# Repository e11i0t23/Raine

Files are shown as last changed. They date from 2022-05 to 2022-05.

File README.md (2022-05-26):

# Raine PCB

PCB for the Raine by AKB, Please note the open source version has a reset button added to underside for compatibility with jlcpcb assembly 

---
##### Please Note these PCBs are provided under the MIT Liscence
---

### How to order
The steps bellow outline how to order this pcb with assembly through the JLCPCB platform  

1) From the releases section download CAMOutputs.zip, BOM_Raine.xlsx, and PNP_Raine_Back.xlsx
2) Load the new order section of Jlcpcb, uploading CamOutputs.zip as gerber file
3) Most settings can be left as defualt, reccomend selecting LeadFree HASL under surface finish,
    (Note only Green or Black soldermask can be used with assembly)
4) Enable PCB assembly, choose wanted quantity, and select assemble bottom side then press next
5) For the Bom upload the file BOM_Raine.xlsx, for CPL upload PNP_Raine_Back.xlsx, then press next
6) Ensure file has loaded and no items show out of stock, then press next followed by add to basket
7) Once PCB has arrived QMK firmware can be flashed

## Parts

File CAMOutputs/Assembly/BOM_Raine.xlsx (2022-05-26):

Qty | Value | Device | Package | LCSC Part Number | Parts
74 | 1n4148W | D_SOD123-SOD-123 | SOD-123 | C81598 | D0, D1, D2, D3, D4, D5, D6, D7, D8, D9, DA, DALT, DB, DBACKSPACE, DBACKSPACE2, DC, DCAPSLOCK, DCTRL, DD, DDEL, DE, DESC, DF, DFN, DG, DH, DI, DINSERT, DJ, DK, DKP_0, DKP_1, DKP_2, DKP_3, DKP_4, DKP_5, DKP_6, DKP_7, DKP_8, DKP_9, DL, DM, DMENU, DN, DNUMLOCK, DO, DP, DQ, DR, DS, DSCROLLLOCK, DSHIFT, DSHIFT2, DSPACE, DSPACE3, DSPACE4, DSPACE6, DSPACE10, DSPACE11, DSPACE12, DSPACE13, DSPACE14, DSPACE15, DSPACE16, DSPACE17, DT, DTAB, DU, DV, DW, DWIN, DX, DY, DZ
4 | 100nf | Capacitor | C0603 | C14663 | C4, C5, C6, C7
2 | 10K | Resistor | R0603 | C25197 | R1, R2
1 | 1uF | Capacitor | C0603 | C15849 | C3
2 | 22omh | Resistor | R0603 | C22961 | R5, R6
2 | 22pF | Capacitor | C0603 | C1653 | C1, C2
1 | 4.7uF | Capacitor | C0603 | C19666 | C8
2 | 5.1k | Resistor | R0603 | C23186 | R3, R4
1 | 16MHZ | Crystal | CR3225 | C13738 | CR1
1 | ATMEGA32U4 | ATMEGA32U4-AUR44ML-L | 44ML-L | C44854 | U2
2 | Reset switch | TL3342F160QG/TR | SW_TL3342F160QG/TR | C388295 | SW1, SW2
1 | USB-C-M12-TYPE-C-31-M12 | USB-C-M12-TYPE-C-31-M12 | TYPE-C-31-M-12 | C165948 | J1

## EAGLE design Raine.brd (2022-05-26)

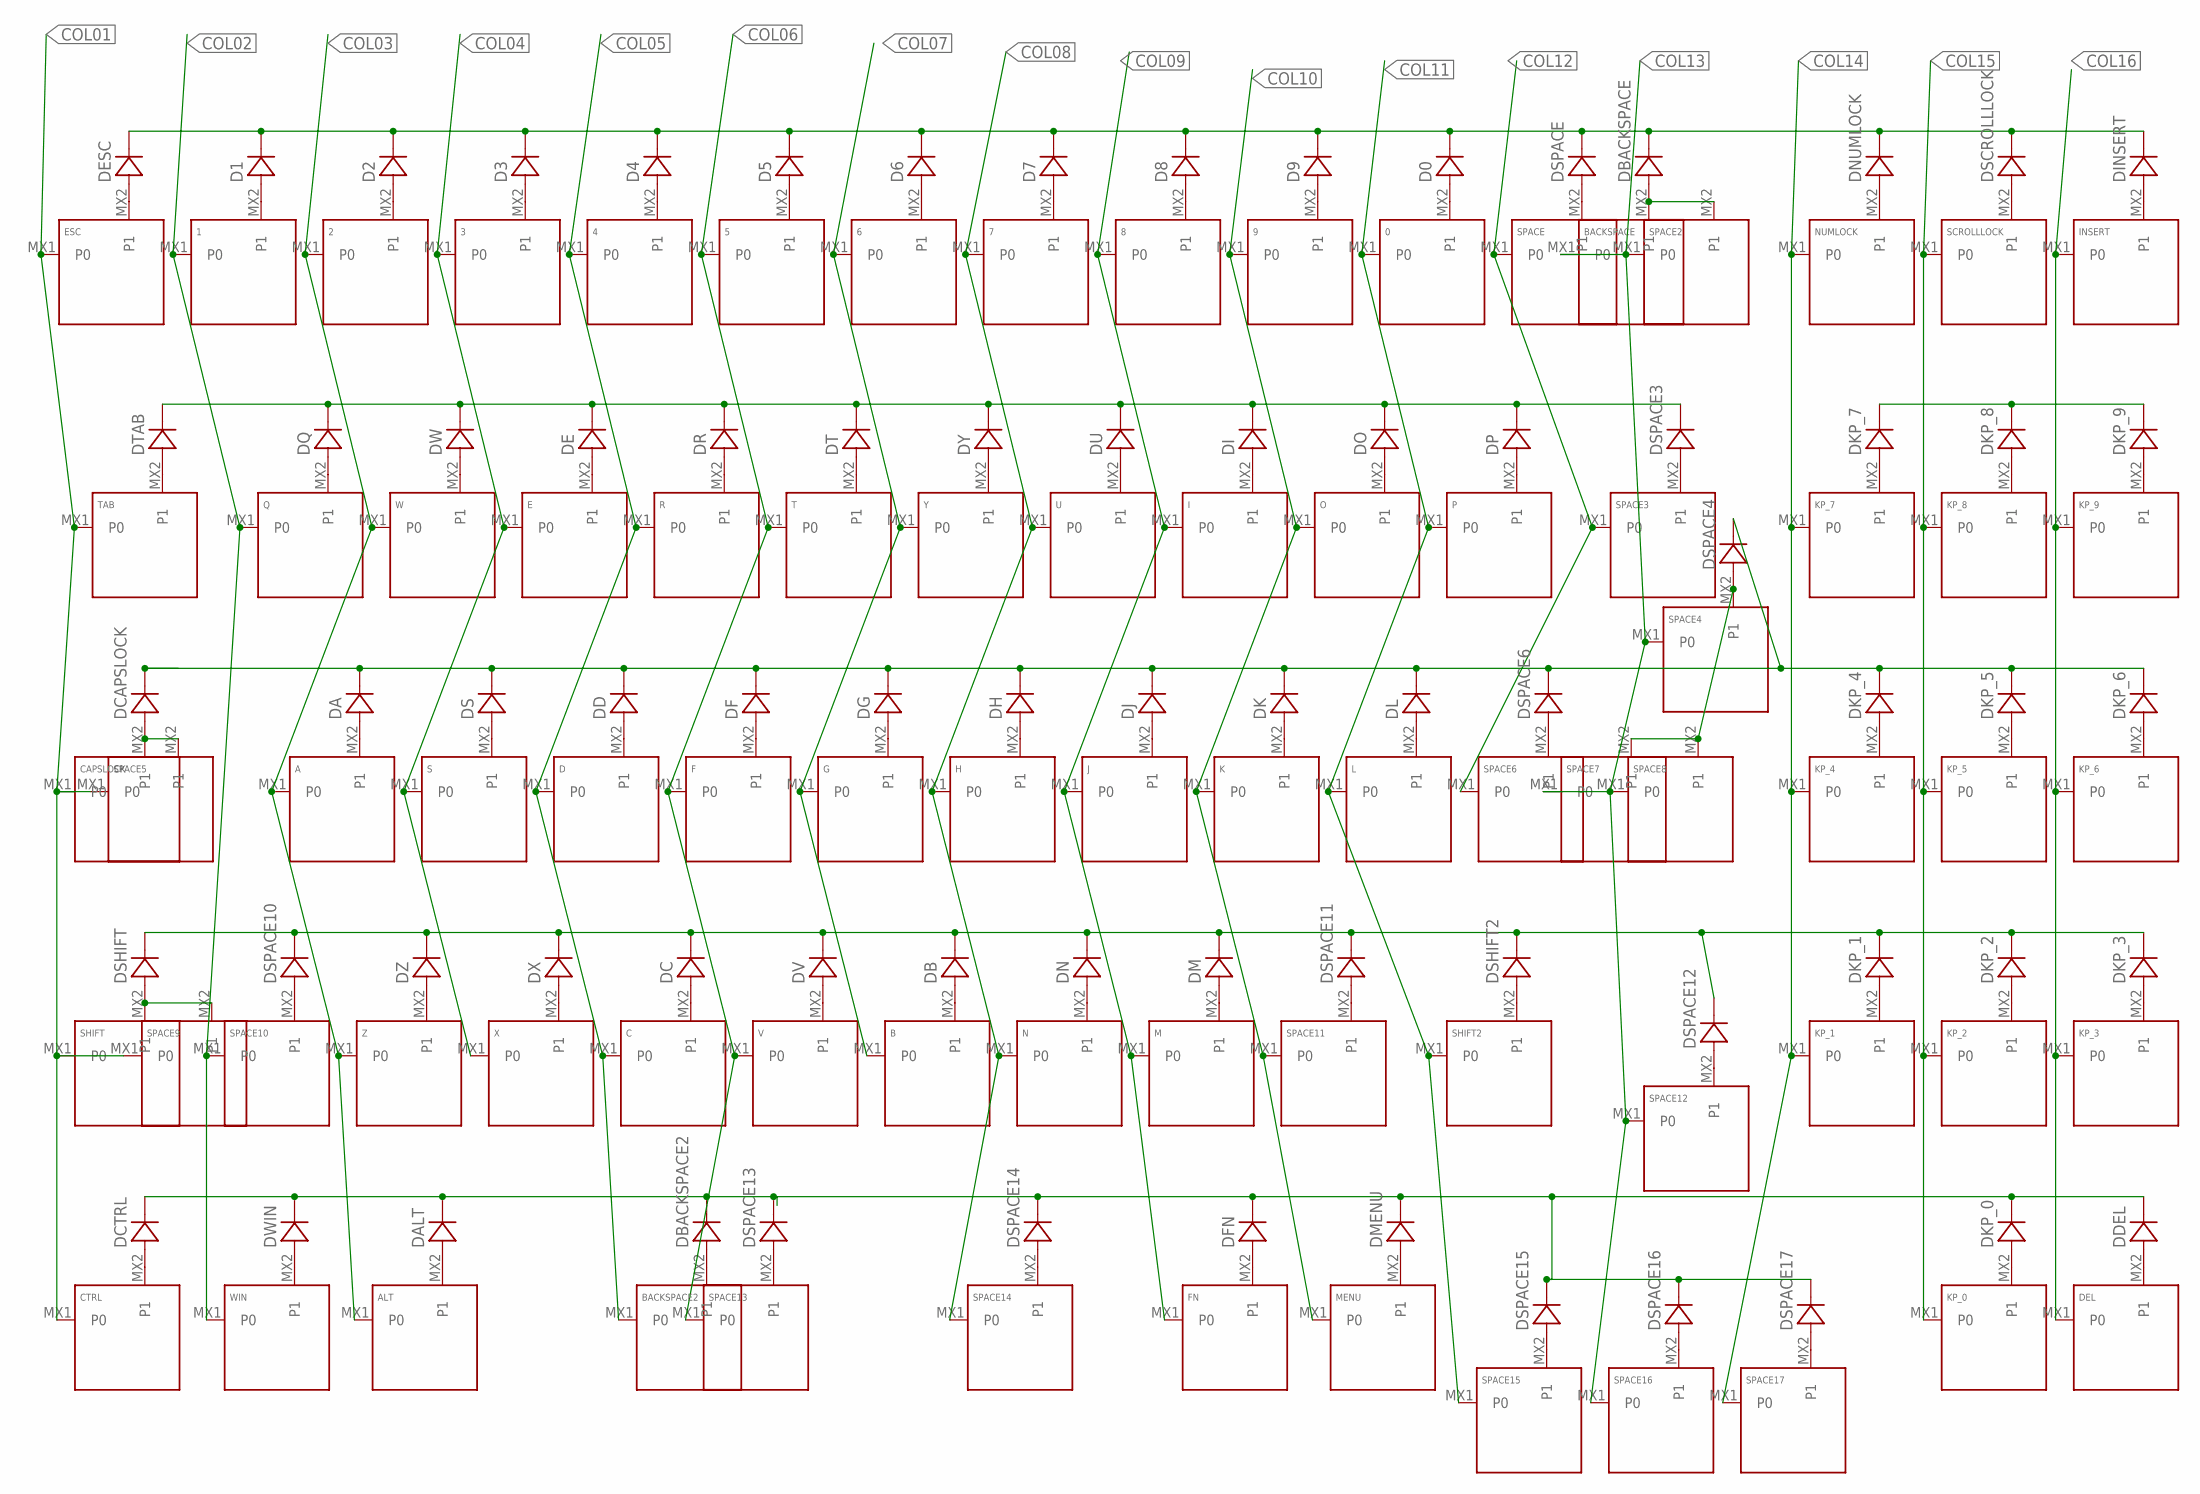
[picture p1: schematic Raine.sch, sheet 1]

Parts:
0, 1, 2, 3, 4, 5, 6, 7, 8, 9: KEYSWITCHMX-1U; MX-1U
A: KEYSWITCHMX-1U; MX-1U
ALT: KEYSWITCHMX-1U; MX-1U
B: KEYSWITCHMX-1U; MX-1U
BACKSPACE: KEYSWITCHMX-2U; MX-2U
BACKSPACE2: KEYSWITCHMX-2U-FLIPPED; MX-2U-FLIPPED
C: KEYSWITCHMX-1U; MX-1U
CAPSLOCK: KEYSWITCHMX-1U; MX-1U
CTRL: KEYSWITCHMX-1U; MX-1U
D: KEYSWITCHMX-1U; MX-1U
D0, D1, D2, D3, D4, D5, D6, D7, D8, D9: D_SOD123-SOD-123; SOD-123
DA: D_SOD123-SOD-123; SOD-123
DALT: D_SOD123-SOD-123; SOD-123
DB: D_SOD123-SOD-123; SOD-123
DBACKSPACE, DBACKSPACE2: D_SOD123-SOD-123; SOD-123
DC: D_SOD123-SOD-123; SOD-123
DCAPSLOCK: D_SOD123-SOD-123; SOD-123
DCTRL: D_SOD123-SOD-123; SOD-123
DD: D_SOD123-SOD-123; SOD-123
DDEL: D_SOD123-SOD-123; SOD-123
DE: D_SOD123-SOD-123; SOD-123
DEL: KEYSWITCHMX-1U; MX-1U
DESC: D_SOD123-SOD-123; SOD-123
DF: D_SOD123-SOD-123; SOD-123
DFN: D_SOD123-SOD-123; SOD-123
DG: D_SOD123-SOD-123; SOD-123
DH: D_SOD123-SOD-123; SOD-123
DI: D_SOD123-SOD-123; SOD-123
DINSERT: D_SOD123-SOD-123; SOD-123
DJ: D_SOD123-SOD-123; SOD-123
DK: D_SOD123-SOD-123; SOD-123
DKP_0, DKP_1, DKP_2, DKP_3, DKP_4, DKP_5, DKP_6, DKP_7, DKP_8, DKP_9: D_SOD123-SOD-123; SOD-123
DL: D_SOD123-SOD-123; SOD-123
DM: D_SOD123-SOD-123; SOD-123
DMENU: D_SOD123-SOD-123; SOD-123
DN: D_SOD123-SOD-123; SOD-123
DNUMLOCK: D_SOD123-SOD-123; SOD-123
DO: D_SOD123-SOD-123; SOD-123
DP: D_SOD123-SOD-123; SOD-123
DQ: D_SOD123-SOD-123; SOD-123
DR: D_SOD123-SOD-123; SOD-123
DS: D_SOD123-SOD-123; SOD-123
DSCROLLLOCK: D_SOD123-SOD-123; SOD-123
DSHIFT, DSHIFT2: D_SOD123-SOD-123; SOD-123
DSPACE, DSPACE3, DSPACE4, DSPACE6, DSPACE10, DSPACE11, DSPACE12, DSPACE13, DSPACE14, DSPACE15, DSPACE16, DSPACE17: D_SOD123-SOD-123; SOD-123
DT: D_SOD123-SOD-123; SOD-123
DTAB: D_SOD123-SOD-123; SOD-123
DU: D_SOD123-SOD-123; SOD-123
DV: D_SOD123-SOD-123; SOD-123
DW: D_SOD123-SOD-123; SOD-123
DWIN: D_SOD123-SOD-123; SOD-123
DX: D_SOD123-SOD-123; SOD-123
DY: D_SOD123-SOD-123; SOD-123
DZ: D_SOD123-SOD-123; SOD-123
E: KEYSWITCHMX-1U; MX-1U
ESC: KEYSWITCHMX-1U; MX-1U
F: KEYSWITCHMX-1U; MX-1U
FN: KEYSWITCHMX-1U; MX-1U
G: KEYSWITCHMX-1U; MX-1U
H: KEYSWITCHMX-1U; MX-1U
I: KEYSWITCHMX-1U; MX-1U
INSERT: KEYSWITCHMX-1U; MX-1U
J: KEYSWITCHMX-1U; MX-1U
K: KEYSWITCHMX-1U; MX-1U
KP_0, KP_1, KP_2, KP_3, KP_4, KP_5, KP_6, KP_7, KP_8, KP_9: KEYSWITCHMX-1U; MX-1U
L: KEYSWITCHMX-1U; MX-1U
M: KEYSWITCHMX-1U; MX-1U
MENU: KEYSWITCHMX-1U; MX-1U
N: KEYSWITCHMX-1U; MX-1U
NUMLOCK: KEYSWITCHMX-1U; MX-1U
O: KEYSWITCHMX-1U; MX-1U
P: KEYSWITCHMX-1U; MX-1U
Q: KEYSWITCHMX-1U; MX-1U
R: KEYSWITCHMX-1U; MX-1U
S: KEYSWITCHMX-1U; MX-1U
SCROLLLOCK: KEYSWITCHMX-1U; MX-1U
SHIFT, SHIFT2: KEYSWITCHMX-1U; MX-1U
SPACE, SPACE2, SPACE3, SPACE5, SPACE6, SPACE8, SPACE10, SPACE11, SPACE12, SPACE15, SPACE16, SPACE17: KEYSWITCHMX-1U; MX-1U
SPACE4, SPACE14: KEYSWITCHMX-2U-FLIPPED; MX-2U-FLIPPED
SPACE7, SPACE9: KEYSWITCHMX-2U; MX-2U
SPACE13: KEYSWITCHMX-6.25U-FLIPPED; MX-6.25U-FLIPPED
T: KEYSWITCHMX-1U; MX-1U
TAB: KEYSWITCHMX-1U; MX-1U
U: KEYSWITCHMX-1U; MX-1U
V: KEYSWITCHMX-1U; MX-1U
W: KEYSWITCHMX-1U; MX-1U
WIN: KEYSWITCHMX-1U; MX-1U
X: KEYSWITCHMX-1U; MX-1U
Y: KEYSWITCHMX-1U; MX-1U
Z: KEYSWITCHMX-1U; MX-1U

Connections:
COL01: CAPSLOCK.MX1 (P0), CTRL.MX1 (P0), ESC.MX1 (P0), SHIFT.MX1 (P0), SPACE5.MX1 (P0), SPACE9.MX1 (P0), TAB.MX1 (P0); also elsewhere on the board
COL02: 1.MX1 (P0), Q.MX1 (P0), SPACE10.MX1 (P0), WIN.MX1 (P0); also elsewhere on the board
COL03: 2.MX1 (P0), A.MX1 (P0), ALT.MX1 (P0), W.MX1 (P0), Z.MX1 (P0); also elsewhere on the board
COL04: 3.MX1 (P0), E.MX1 (P0), S.MX1 (P0), X.MX1 (P0); also elsewhere on the board
COL05: 4.MX1 (P0), BACKSPACE2.MX1 (P0), C.MX1 (P0), D.MX1 (P0), R.MX1 (P0); also elsewhere on the board
COL06: 5.MX1 (P0), F.MX1 (P0), SPACE13.MX1 (P0), T.MX1 (P0), V.MX1 (P0); also elsewhere on the board
COL07: 6.MX1 (P0), B.MX1 (P0), G.MX1 (P0), Y.MX1 (P0); also elsewhere on the board
COL08: 7.MX1 (P0), H.MX1 (P0), N.MX1 (P0), SPACE14.MX1 (P0), U.MX1 (P0); also elsewhere on the board
COL09: 8.MX1 (P0), FN.MX1 (P0), I.MX1 (P0), J.MX1 (P0), M.MX1 (P0); also elsewhere on the board
COL10: 9.MX1 (P0), K.MX1 (P0), MENU.MX1 (P0), O.MX1 (P0), SPACE11.MX1 (P0); also elsewhere on the board
COL11: 0.MX1 (P0), L.MX1 (P0), P.MX1 (P0), SHIFT2.MX1 (P0), SPACE15.MX1 (P0); also elsewhere on the board
COL12: SPACE.MX1 (P0), SPACE3.MX1 (P0), SPACE6.MX1 (P0); also elsewhere on the board
COL13: BACKSPACE.MX1 (P0), SPACE2.MX1 (P0), SPACE4.MX1 (P0), SPACE7.MX1 (P0), SPACE8.MX1 (P0), SPACE12.MX1 (P0), SPACE16.MX1 (P0); also elsewhere on the board
COL14: KP_1.MX1 (P0), KP_4.MX1 (P0), KP_7.MX1 (P0), NUMLOCK.MX1 (P0), SPACE17.MX1 (P0); also elsewhere on the board
COL15: KP_0.MX1 (P0), KP_2.MX1 (P0), KP_5.MX1 (P0), KP_8.MX1 (P0), SCROLLLOCK.MX1 (P0); also elsewhere on the board
COL16: DEL.MX1 (P0), INSERT.MX1 (P0), KP_3.MX1 (P0), KP_6.MX1 (P0), KP_9.MX1 (P0); also elsewhere on the board
unnamed: DTAB.A, TAB.MX2 (P1)
unnamed: DQ.A, Q.MX2 (P1)
unnamed: DW.A, W.MX2 (P1)
unnamed: DE.A, E.MX2 (P1)
unnamed: DR.A, R.MX2 (P1)
unnamed: DT.A, T.MX2 (P1)
unnamed: DY.A, Y.MX2 (P1)
unnamed: DU.A, U.MX2 (P1)
unnamed: DI.A, I.MX2 (P1)
unnamed: DO.A, O.MX2 (P1)
unnamed: DP.A, P.MX2 (P1)
unnamed: DSPACE3.A, SPACE3.MX2 (P1)
unnamed: DKP_7.A, KP_7.MX2 (P1)
unnamed: DKP_8.A, KP_8.MX2 (P1)
unnamed: DKP_9.A, KP_9.MX2 (P1)
unnamed: DNUMLOCK.A, NUMLOCK.MX2 (P1)
unnamed: CAPSLOCK.MX2 (P1), DCAPSLOCK.A, SPACE5.MX2 (P1)
unnamed: A.MX2 (P1), DA.A
unnamed: DS.A, S.MX2 (P1)
unnamed: D.MX2 (P1), DD.A
unnamed: DF.A, F.MX2 (P1)
unnamed: DG.A, G.MX2 (P1)
unnamed: DH.A, H.MX2 (P1)
unnamed: DJ.A, J.MX2 (P1)
unnamed: DK.A, K.MX2 (P1)
unnamed: DL.A, L.MX2 (P1)
unnamed: DSPACE6.A, SPACE6.MX2 (P1)
unnamed: DSPACE4.A, SPACE4.MX2 (P1), SPACE7.MX2 (P1), SPACE8.MX2 (P1)
unnamed: DSCROLLLOCK.A, SCROLLLOCK.MX2 (P1)
unnamed: DKP_4.A, KP_4.MX2 (P1)
unnamed: DKP_5.A, KP_5.MX2 (P1)
unnamed: DKP_6.A, KP_6.MX2 (P1)
unnamed: DSHIFT.A, SHIFT.MX2 (P1), SPACE9.MX2 (P1)
unnamed: DINSERT.A, INSERT.MX2 (P1)
unnamed: DSPACE10.A, SPACE10.MX2 (P1)
unnamed: DZ.A, Z.MX2 (P1)
unnamed: DX.A, X.MX2 (P1)
unnamed: C.MX2 (P1), DC.A
unnamed: DV.A, V.MX2 (P1)
unnamed: B.MX2 (P1), DB.A
unnamed: DN.A, N.MX2 (P1)
unnamed: DM.A, M.MX2 (P1)
unnamed: DSPACE11.A, SPACE11.MX2 (P1)
unnamed: DSHIFT2.A, SHIFT2.MX2 (P1)
unnamed: DKP_1.A, KP_1.MX2 (P1)
unnamed: DKP_2.A, KP_2.MX2 (P1)
unnamed: DKP_3.A, KP_3.MX2 (P1)
unnamed: DSPACE12.A, SPACE12.MX2 (P1)
unnamed: CTRL.MX2 (P1), DCTRL.A
unnamed: DWIN.A, WIN.MX2 (P1)
unnamed: ALT.MX2 (P1), DALT.A
unnamed: DSPACE13.A, SPACE13.MX2 (P1)
unnamed: BACKSPACE2.MX2 (P1), DBACKSPACE2.A
unnamed: DSPACE14.A, SPACE14.MX2 (P1)
unnamed: DFN.A, FN.MX2 (P1)
unnamed: DMENU.A, MENU.MX2 (P1)
unnamed: DKP_0.A, KP_0.MX2 (P1)
unnamed: DDEL.A, DEL.MX2 (P1)
unnamed: DSPACE15.A, SPACE15.MX2 (P1)
unnamed: DSPACE16.A, SPACE16.MX2 (P1)
unnamed: DSPACE17.A, SPACE17.MX2 (P1)
unnamed: DSPACE.A, SPACE.MX2 (P1)
unnamed: 0.MX2 (P1), D0.A
unnamed: 9.MX2 (P1), D9.A
unnamed: 8.MX2 (P1), D8.A
unnamed: 7.MX2 (P1), D7.A
unnamed: 6.MX2 (P1), D6.A
unnamed: 5.MX2 (P1), D5.A
unnamed: DESC.A, ESC.MX2 (P1)
unnamed: 1.MX2 (P1), D1.A
unnamed: 2.MX2 (P1), D2.A
unnamed: 3.MX2 (P1), D3.A
unnamed: 4.MX2 (P1), D4.A
unnamed: BACKSPACE.MX2 (P1), DBACKSPACE.A, SPACE2.MX2 (P1)
ROW1: D0.C, D1.C, D2.C, D3.C, D4.C, D5.C, D6.C, D7.C, D8.C, D9.C, DBACKSPACE.C, DESC.C, DINSERT.C, DNUMLOCK.C, DSCROLLLOCK.C, DSPACE.C; also elsewhere on the board
ROW2: DE.C, DI.C, DKP_7.C, DKP_8.C, DKP_9.C, DO.C, DP.C, DQ.C, DR.C, DSPACE3.C, DT.C, DTAB.C, DU.C, DW.C, DY.C; also elsewhere on the board
ROW3: DA.C, DCAPSLOCK.C, DD.C, DF.C, DG.C, DH.C, DJ.C, DK.C, DKP_4.C, DKP_5.C, DKP_6.C, DL.C, DS.C, DSPACE4.C, DSPACE6.C; also elsewhere on the board
ROW4: DB.C, DC.C, DKP_1.C, DKP_2.C, DKP_3.C, DM.C, DN.C, DSHIFT.C, DSHIFT2.C, DSPACE10.C, DSPACE11.C, DSPACE12.C, DV.C, DX.C, DZ.C; also elsewhere on the board
ROW5.25: DALT.C, DBACKSPACE2.C, DCTRL.C, DDEL.C, DFN.C, DKP_0.C, DMENU.C, DSPACE13.C, DSPACE14.C, DSPACE15.C, DSPACE16.C, DSPACE17.C, DWIN.C; also elsewhere on the board

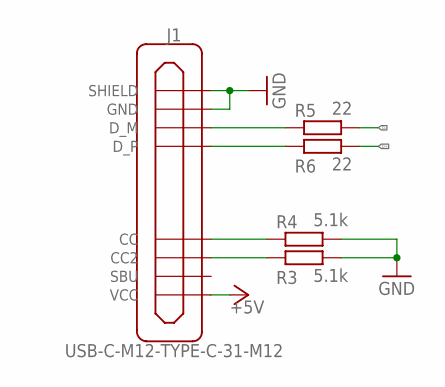
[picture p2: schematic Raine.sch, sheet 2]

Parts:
J1: USB-C-M12-TYPE-C-31-M12; TYPE-C-31-M-12
R3, R4: 5.1k; CAPC1608X90
R5, R6: 22; CAPC1608X90

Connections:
+5V: J1.P$2 (VCC), J1.P$11 (VCC); also elsewhere on the board
D+: R6.2; also elsewhere on the board
D-: R5.2; also elsewhere on the board
GND: J1.P$1 (GND), J1.P$12 (GND), J1.P$13 (SHIELD), J1.P$14 (SHIELD), J1.P$15 (SHIELD), J1.P$16 (SHIELD), R3.2, R4.2; also elsewhere on the board
unnamed: J1.P$6 (D_P), J1.P$8 (D_P), R6.1
unnamed: J1.P$5 (D_M), J1.P$7 (D_M), R5.1
unnamed: J1.P$10 (CC2), R3.1
unnamed: J1.P$4 (CC), R4.1

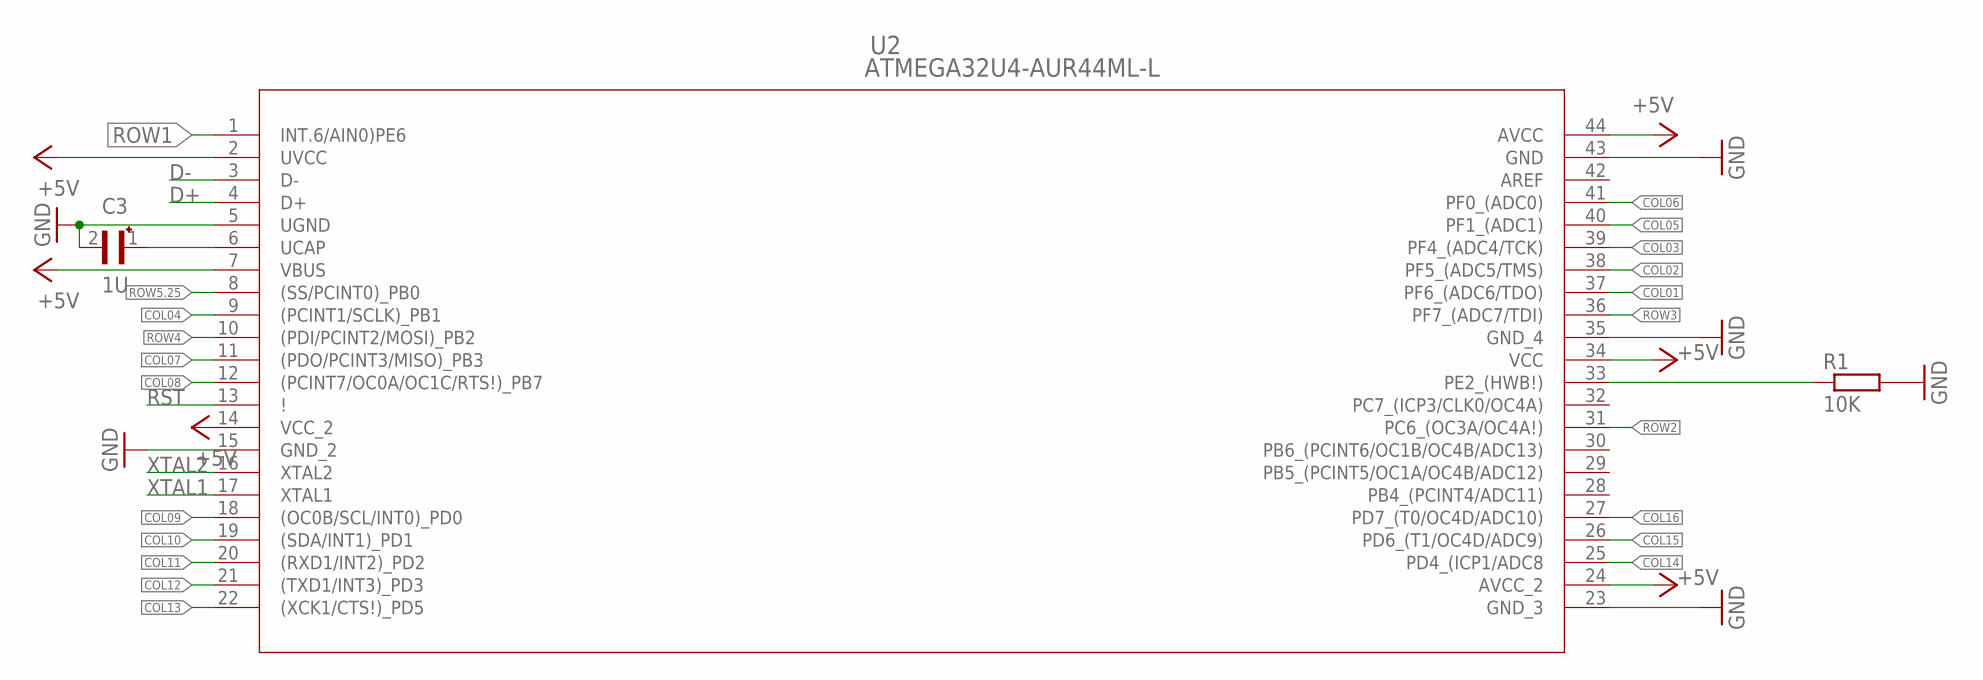
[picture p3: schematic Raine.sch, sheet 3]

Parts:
C3: 1U; CAPC1608X90
R1: 10K; CAPC1608X90
U2: ATMEGA32U4-AUR44ML-L; 44ML-L

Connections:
+5V: U2.2 (UVCC), U2.7 (VBUS), U2.14 (VCC_2), U2.24 (AVCC_2), U2.34 (VCC), U2.44 (AVCC); also elsewhere on the board
COL01: U2.37 (PF6_(ADC6/TDO)); also elsewhere on the board
COL02: U2.38 (PF5_(ADC5/TMS)); also elsewhere on the board
COL03: U2.39 (PF4_(ADC4/TCK)); also elsewhere on the board
COL04: U2.9 ((PCINT1/SCLK)_PB1); also elsewhere on the board
COL05: U2.40 (PF1_(ADC1)); also elsewhere on the board
COL06: U2.41 (PF0_(ADC0)); also elsewhere on the board
COL07: U2.11 ((PDO/PCINT3/MISO)_PB3); also elsewhere on the board
COL08: U2.12 ((PCINT7/OC0A/OC1C/RTS!)_PB7); also elsewhere on the board
COL09: U2.18 ((OC0B/SCL/INT0)_PD0); also elsewhere on the board
COL10: U2.19 ((SDA/INT1)_PD1); also elsewhere on the board
COL11: U2.20 ((RXD1/INT2)_PD2); also elsewhere on the board
COL12: U2.21 ((TXD1/INT3)_PD3); also elsewhere on the board
COL13: U2.22 ((XCK1/CTS!)_PD5); also elsewhere on the board
COL14: U2.25 (PD4_(ICP1/ADC8); also elsewhere on the board
COL15: U2.26 (PD6_(T1/OC4D/ADC9)); also elsewhere on the board
COL16: U2.27 (PD7_(T0/OC4D/ADC10)); also elsewhere on the board
D+: U2.4 (D+); also elsewhere on the board
D-: U2.3 (D-); also elsewhere on the board
GND: C3.2, R1.2, U2.5 (UGND), U2.15 (GND_2), U2.23 (GND_3), U2.35 (GND_4), U2.43 (GND); also elsewhere on the board
unnamed: C3.1, U2.6 (UCAP)
unnamed: R1.1, U2.33 (PE2_(HWB!))
ROW1: U2.1 (INT.6/AIN0)PE6); also elsewhere on the board
ROW2: U2.31 (PC6_(OC3A/OC4A!)); also elsewhere on the board
ROW3: U2.36 (PF7_(ADC7/TDI)); also elsewhere on the board
ROW4: U2.10 ((PDI/PCINT2/MOSI)_PB2); also elsewhere on the board
ROW5.25: U2.8 ((SS/PCINT0)_PB0); also elsewhere on the board
RST: U2.13 (!); also elsewhere on the board
XTAL1: U2.17 (XTAL1); also elsewhere on the board
XTAL2: U2.16 (XTAL2); also elsewhere on the board

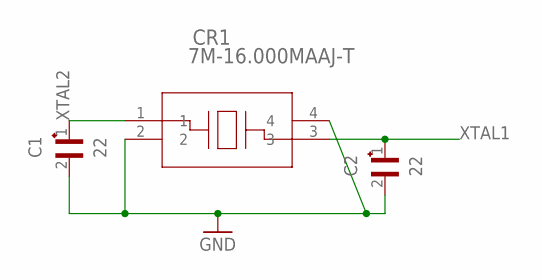
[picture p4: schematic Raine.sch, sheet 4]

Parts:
C1, C2: 22; CAPC1608X90
CR1: 7M-16.000MAAJ-T; CRYSTAL_TXC_7M

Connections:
GND: C1.2, C2.2, CR1.2, CR1.4; also elsewhere on the board
XTAL1: C2.1, CR1.3; also elsewhere on the board
XTAL2: C1.1, CR1.1; also elsewhere on the board

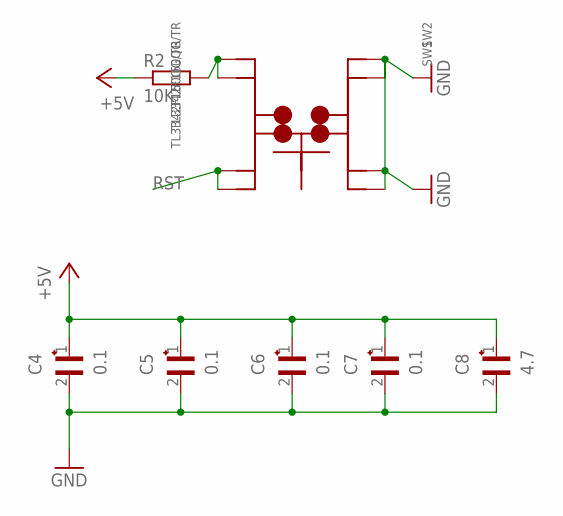
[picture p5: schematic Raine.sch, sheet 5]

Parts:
C4, C5, C6, C7: 0.1; CAPC1608X90
C8: 4.7; CAPC1608X90
R2: 10K; CAPC1608X90
SW1, SW2: TL3342F160QG/TR; SW_TL3342F160QG/TR

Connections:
+5V: C4.1, C5.1, C6.1, C7.1, C8.1, R2.1; also elsewhere on the board
GND: C4.2, C5.2, C6.2, C7.2, C8.2, SW1.3, SW1.4, SW2.3, SW2.4; also elsewhere on the board
unnamed: R2.2, SW1.1, SW2.1
RST: SW1.2, SW2.2; also elsewhere on the board

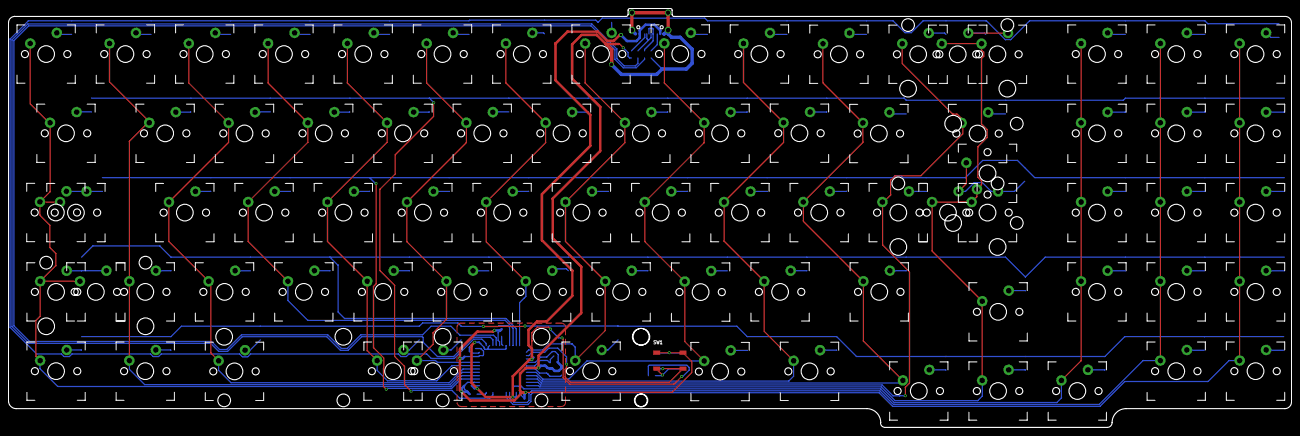
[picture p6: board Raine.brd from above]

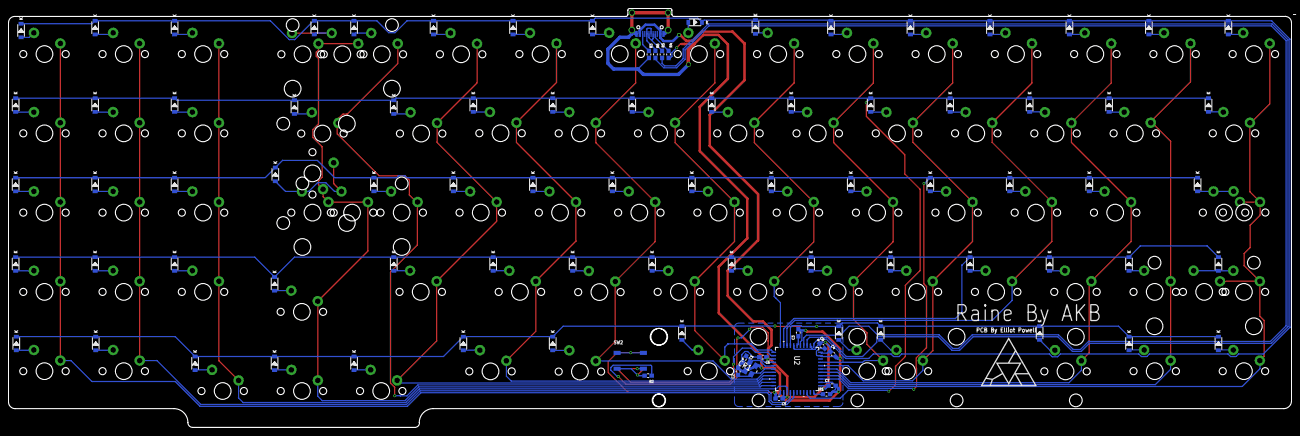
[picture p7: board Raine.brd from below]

Board: 2 copper layers, 307.5 x 100.4 mm, 172 parts (91 on the bottom side), 109 nets.

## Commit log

2022-05-15 minor trace moves
    [PnP_Raine_back.csv, PnP_Raine_front.csv, Raine.brd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]
2022-05-26 Add reset switch to bottom of pcb
    [Raine.brd, Raine.sch]
2022-05-26 Update Production files
    [BOM_Raine.xlsx, PnP_Raine_back.csv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]
2022-05-26 Update for JLCPCB
    [BOM_Raine.xlsx, PnP_Raine_back.csv, PnP_Raine_back.xlsx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]
